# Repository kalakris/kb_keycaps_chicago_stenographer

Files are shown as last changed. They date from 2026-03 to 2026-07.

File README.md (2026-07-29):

<!-- omit from toc -->
# Chicago Stenographer Keycaps - Optimized for JLCPCB 3D printing

This fork combines multiple chicago stenographer keycaps with sprues into one file to get around the $1 minimum charge of JLCPCB.

If you like these keycaps after trying the 3D printed version, [consider buying original versions from the creator at asymplex.xyz](https://www.asymplex.xyz).

<!-- omit from toc -->
## Table Of Contents

- [1. Photos](#1-photos)
- [2. About this fork](#2-about-this-fork)
- [3. Documentation](#3-documentation)
  - [3.1. Keycap Types](#31-keycap-types)
    - [3.1.1. R2 Keycaps - Top](#311-r2-keycaps---top)
    - [3.1.2. R3 Keycaps - Middle rows and home row](#312-r3-keycaps---middle-rows-and-home-row)
    - [3.1.3. R4 Keycaps - Bottom](#313-r4-keycaps---bottom)
    - [3.1.4. Thumb Keycaps](#314-thumb-keycaps)
    - [3.1.5. 1.5u Thumb Key](#315-15u-thumb-key)
    - [3.1.6. Convex Keycaps](#316-convex-keycaps)
    - [3.1.7. Lateral Keycaps](#317-lateral-keycaps)
    - [3.1.8. Trapezoidal Sector Keycaps](#318-trapezoidal-sector-keycaps)
    - [3.1.9. Extended R5 Keys](#319-extended-r5-keys)
  - [3.2. What to print...](#32-what-to-print)
    - [3.2.1. If you have a 5x3 row board (Such as the corne without the outer coulmn)](#321-if-you-have-a-5x3-row-board-such-as-the-corne-without-the-outer-coulmn)
    - [3.2.2. If you have a 6x3 row board (Such as the corne WITH the outer coulmn)](#322-if-you-have-a-6x3-row-board-such-as-the-corne-with-the-outer-coulmn)
    - [3.2.3. If you have a 6x4 board with a num row...](#323-if-you-have-a-6x4-board-with-a-num-row)
  - [3.3. How to order on JLCPCB](#33-how-to-order-on-jlcpcb)
  - [3.4. How to create custom sets of keycaps](#34-how-to-create-custom-sets-of-keycaps)

## 1. Photos

Here are some photos of my prints using JLC 3DP's MJF PA12-HP Nylon process:

Chicago Stenographer 3D Print - MJF

Chicago Stenographer 3D Print - MJF

## 2. About this fork

This is a fork of [sporkus/PseudoMakeMeKeyCapProfiles](https://github.com/sporkus/PseudoMakeMeKeyCapProfiles/), which is a fork of [pseudoku's original chicago stenographer keycaps](https://github.com/pseudoku/PseudoMakeMeKeyCapProfiles).

Sporkus is the one who came up with the idea and the code to add spuers to the keycaps.

I expanded on those efforts in the following ways...

* Added support to generate rows of varying keycaps
* Fixed the 1.5u inner thumb key that is used in many corne-like boards
* Added the homing bar option to the lateral keys
* Added documentation on how to print the keycaps
* Fixed openscad warnings

Screenshot of thumbs stl

Screenshot of thumbs back stl

## 3. Documentation

### 3.1. Keycap Types

When I first started looking into these keycaps, I was incredibly confused by all the available keycap variations and files.

This repo is my attempt to simplify and document what I learned.

In the MX keycap world Rx is used to refer to rows and keycap heights. As someone who was only using Choc keycaps in the ergo keyboard world that was not intuitive for me at all.

But this graphic [from melgeek](https://www.melgeek.com/blogs/guide/the-type-of-keycaps-profiles) explains it well:
Keycap Rows

#### 3.1.1. R2 Keycaps - Top

You use these keycaps for the top row, but for the CS keycap set, both R2 and R4 are the same. You simply flip them around.

I also included pre-rotated keycaps as R4, but you can also just print R2 twice.

If your keyboard has a num row, you would use them for the num row and the bottom alpha row.

If you have a corne-style keyboard with just three rows, you would use it for the top and bottom alpha rows.

#### 3.1.2. R3 Keycaps - Middle rows and home row

You use these keycaps for the columns between the top and bottom rows.

If you have a num row, you would use it for the top alpha row and the homerow.

If you have a corne-style keyboard with just three rows, you would use it just for the home row.

#### 3.1.3. R4 Keycaps - Bottom

As explained in the R2 section, these are exactly the same as the R2 files, but pre-rotated.

You can order 2x R2 or 1x R2 + 1x R4.

#### 3.1.4. Thumb Keycaps

The thumb keycaps are designed to create a "dish" with ridges on the outer thumb keys.

The same model is used for the left and right keys, but it is mirrored. In this repo you will find a model that already has all the versions you will need.

If you have a corne-style thumb cluster with 3 keys, you can use a convex key for the middle one. It will act like a homing key.

And there is an alternative convex key included, which is slightly lower so that you can see which one you like better.

#### 3.1.5. 1.5u Thumb Key

Additionally, there are also 1.5u variations of the outer thumb keys.

You have to be very careful if you get the files from other repos, because by default the stem is rotated by 90 degrees unlike regular 1.5u keys.

The files here have the stem in the correct orientation for keyboards like the corne where the switch is already rotated by 90 degrees.

#### 3.1.6. Convex Keycaps

The convex keys are used on the middle thumb keys, but can also optionally be used on the inner and outer columns.

You can [see an example of how that looks here](https://www.printables.com/model/158865-chicago-steno-low-profile-ergo-keycaps).

#### 3.1.7. Lateral Keycaps

Steno keycaps have vertical ridges that keep your finger aligned in the row. This is great, but some people prefer to not have these ridges for the inner and outer columns so that they don't have to lift the finger to reach the side-key or to perform horizontal combos with one finger.

Keep in mind, that the lateral keycaps are used as a pair on two columns next to each other.

The file contains only one set of the two. If you want it on both sides of the keyboard, you have to print it twice.

I suggest printing one version with the homing dots and another with the homing bars to get all possible variations.

#### 3.1.8. Trapezoidal Sector Keycaps

For keyboards with splayed thumb keys arranged on a circular arc (such as the Go60), standard rectangular keycaps leave wedge-shaped gaps. The trapezoidal sector keycaps (`Choc_Chicago_Steno_Thumb_Trap.scad`) fill these gaps with sector-shaped footprints:

- Wider on the outer edge (away from arc center), narrower on the inner edge
- Arced outer/inner edges following the thumb arc curvature
- Radial side edges pointing toward the arc center

Three variants are available:

| Keycap ID | Position | Profile | Notes |
|---|---|---|---|
| `cs_t_trap_convex_t1` | T1 (innermost) | Convex dome | Symmetric 1.25u depth sector; inner edge aligned to C1 column above |
| `cs_t_trap_convex` | T2 (middle) | Convex dome | Symmetric 1.25u depth sector |
| `cs_t_trap_thumb_l/r` | T3 (outermost) | Thumb scoop | Symmetric 1.25u depth sector, L/R mirrored |

The arc geometry parameters (radius, angular spacing, gap) are configured in the file and default to Go60 measurements. Open `go60_visualization.scad` to see them in context.

#### 3.1.9. Extended R5 Keys

For boards where the splayed thumb row meets a row of straight-shifted keys, the extended R5 keys (`cs_r3x_1_ext_a`, `cs_r3x_1_ext_b` in `Choc_Chicago_Steno_Convex.scad`) extend the body downward so the bottom edge aligns with T1's inner edge:

| Keycap ID | Extension | Used for |
|---|---|---|
| `cs_r3x_1_ext_a` | +3.6mm | C4 R5 and C2 R5 columns |
| `cs_r3x_1_ext_b` | +6.5mm | C3 R5 column |

The body is symmetric (centered at `BodyOffsetY`) and the stem is offset to align with the switch position. From above, these look like standard symmetric convex keys; from the bottom, the stem is visibly off-center.

These are used in the V2 thumb row layout (`left_thumb_keys_v2` in `go60_visualization.scad`).

> **Known gap:** all three extended keys are convex, so V2 puts a dome on C2 R5.
> V1 (`left_thumb_keys`) deliberately uses a thumb dish (`cs_t_1_l`) there, since
> the thumb rests on T1 and reaches C2 R5 while C3/C4 R5 are finger keys. C2 R5 is
> convex in V2 only because `BodyOffsetY` lives in `Choc_Chicago_Steno_Convex.scad`
> and no extended thumb variant exists yet. Fixing it means porting `BodyOffsetY`
> into the thumb file, where the 7mm scoop is likely to spike the same way `ext_b`
> did.

### 3.2. What to print...

Look at the `export_*.scad` files to see what key models were used and further comments on how to use the sets. Render them with OpenSCAD to generate STL files (STLs are not checked into git due to size).

#### 3.2.1. If you have a 5x3 row board (Such as the corne without the outer coulmn)

* 1x `cs_row_r2_top.stl`
* 1x `cs_row_r3_homerow_bar.stl` or `cs_row_r3_homerow_dots.stl` (different homing keys)
  * Or the `cs_row_r3_regular.stl` and `cs_row_r3_homing_only.stl` to get both homing key variations
* 1x `cs_row_r4_bottom.stl`
* 1x `cs_row_thumbs.stl`

#### 3.2.2. If you have a 6x3 row board (Such as the corne WITH the outer coulmn)

All of the above, PLUS...

* 1x `cs_column_regular.stl` or `cs_column_convex.stl` for the outer pinky column

You can also print the `cs_column_regular_with_homing_bars.stl` variation which contains two more homing key.

Combine it with the `cs_row_r3_homerow_dots.scad` to get both homing key variations without needing to print them separately.

Alternatively, you can also consider the lateral variation, but this one needs to be printed twice as it should be used on both the outer and pinky keys.

The leeve rows can also be used for the index and inner column as the stl includes homing key variations.

To be able to use lateral keys on both sides and get both types of homing keys you should print...

* 1x `cs_column_lateral_homing_bar.stl`
* 1x `cs_column_lateral_homing_dot.stl`

#### 3.2.3. If you have a 6x4 board with a num row...

All of the above, PLUS...

* 1x `cs_row_r3_regular.stl` for the top alpha row (the r2 keycaps will be used for the num row)

#### 3.2.4. If you have a MoErgo Go60 (6x4 split columnar)

The Go60 has 6 columns x 4 rows per half plus a 6-key thumb cluster. C1, C2 (inner index pair) and C5, C6 (outer pinky pair) can each be printed in two styles — **lateral** (smooth side, easier to slide between adjacent columns) or **non-lateral** (ridged, like the rest of the steno set). Print one or both styles depending on preference; the table below covers both.

| File | Keys | Qty | Subtotal | Notes |
|---|---|-----|---|---|
| `export_go60_regular_columns.scad` | 10 | 4 | 40 | C3+C4 (×2 halves) + non-lateral C5+C6 (×2 halves). R1-R4 ridged + 2 spare convex thumbs. Render with CGAL. |
| `export_go60_regular_columns_homing.scad` | 10 | 2 | 20 | Non-lateral C1+C2 (×2 halves). R1-R4 ridged + homing bar + homing dot for C2 R3. |
| `export_go60_lateral_columns.scad` | 10 | 2 | 20 | Lateral C5+C6 (×2 halves). Lateral R1-R4 + 2 spare ridged thumbs. |
| `export_go60_inner_columns_left.scad` | 10 | 1 | 10 | Lateral C2+C1 left half. Lateral R1-R4 + homing bar + homing dot. |
| `export_go60_inner_columns_right.scad` | 10 | 1 | 10 | Lateral C2+C1 right half. Lateral R1-R4 + homing bar + homing dot. |
| `export_go60_thumbs.scad` | 10 | 1 | 10 | Main thumb cluster: ridged + convex + spare convex. Render with CGAL. |
| `export_go60_thumbs_alt.scad` | 10 | 1 | 10 | Alt thumb cluster: 8 convex R2 + 2 thumb 1.25u. Render with CGAL. |
| **Total (both styles)** | | | **120** | |

If you only want one style, drop the corresponding plates: skip the lateral plates (`lateral_columns`, `inner_columns_left`, `inner_columns_right`) for non-lateral only, or skip 4 of the 6 non-lateral plates (keep `regular_columns` ×2 for C3+C4) for lateral only.

Plates marked "Render with CGAL" contain convex keys that require the CGAL backend (`openscad --backend=CGAL`). Other plates can use the faster Manifold backend.

Open `go60_visualization.scad` in OpenSCAD to preview the full keyboard layout with all keys at their approximate positions. The visualization uses trapezoidal sector keycaps for the splayed thumb positions (T1, T2, T3) — see [Trapezoidal Sector Keycaps](#318-trapezoidal-sector-keycaps).

### 3.3. How to order on JLCPCB

* Upload the stl model
* Select 3D Technology: `MJF (Nylon)`
* Select Material: `PA12-HP Nylon`
* Optionally select Surface Finish: `Add - Dyeing - Dyed Black` to get black keycaps.
  * Without this they will be a "textured gray"
* Make sure to select the correct Quantity

The total for a 6x4 board with all the optional stuff will cost appoximately $23.88. In addition to that JLC now charges $1 per sprued file [as per their connected parts policy](https://jlc3dp.com/help/article/213-Connected-Parts-Printing-Guide).

So, it will be approximately $32.88 + shipping in total.

> [!NOTE]
> You will likely get warnings that some areas on the 1.5u thumb keys are too thin.
>
> You can just tell them that you accept the risk and it will print just fine. Me and several other people successfully printed these keycaps despite the warnings.
>
> The original code for the 1.5u thumb keys produced keycaps with the wrong stem orientation. I have attempted to fix this problem, but JLCPCB still complains about areas that are too thin and will ask you if you want to take the risk of them not getting printed correctly when you order.
>
> All other keycaps should not have problems though.

#### 3.3.1. JLCPCB Shopping Cart Example  <!-- omit from toc -->

JLCPCB Shopping Cart Example

### 3.4. How to create custom sets of keycaps

* Install OpenSCAD
  * The [snaphot version](https://openscad.org/downloads.html#snapshots) is recommended for performance reasons
  * If it crashes, [try an older version of the snapshot](https://files.openscad.org/snapshots/)
* Set up the dev environment
  * Adjust the Makefile with the path to your OpenSCAD installation
  * Unzip the `libraries.zip` into your [OpenSCAD library path](https://en.wikibooks.org/wiki/OpenSCAD_User_Manual/Libraries)
* Create your keycap set
  * Copy one of the files starting with `export_`
  * Adjust the keycaps you want to use. Available options are in `gen_sprued_keycaps.scad`
  * Keep in mind that jlcpcb only allows a maximum of 10 keycaps per file
* Generate STLs
  * Run `make` and it will generate all missing STLs
  * Alternatively you can also select which file to generate by running something like `make stl/cs_row_thumbs.stl`, but keep in mind that you have to use the file name of the final stl file and not of the source `.scad` file
  * STLs are exported in binary format (`--export-format binstl`) which is ~6x smaller than ASCII STL. If you render manually, add this flag to keep file sizes manageable (e.g. ~40 MB vs ~250 MB for a 10-key plate).

Alternatively you can also run the GUI version, but it's a bit slow.

You can speed it up by enabling the `manifold` options in `Preferences -> Features` (Snapshot version only).

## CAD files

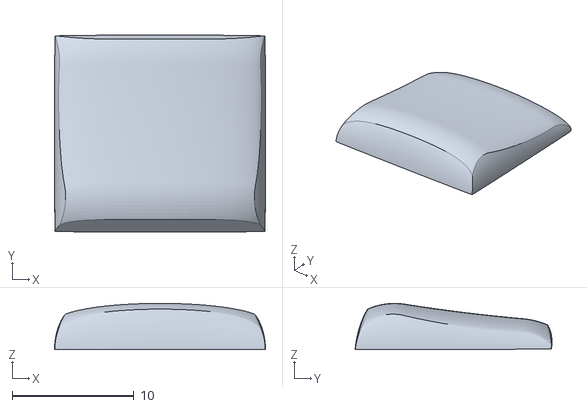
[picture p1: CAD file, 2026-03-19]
stl/single_keys/cs_r4x_1.stl
17.3 x 16.2 x 3.79

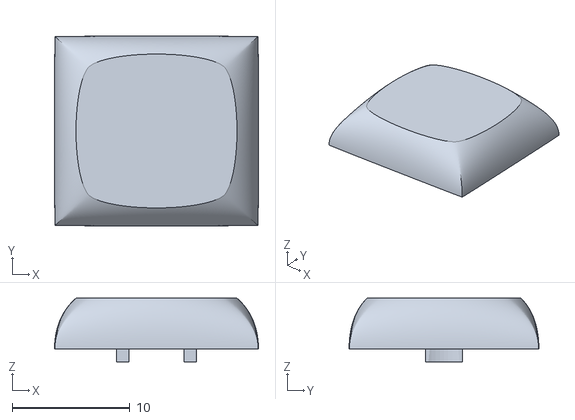
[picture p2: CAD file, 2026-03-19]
stl/single_keys/cs_r3x_1.stl
17.3 x 16.1 x 5.41

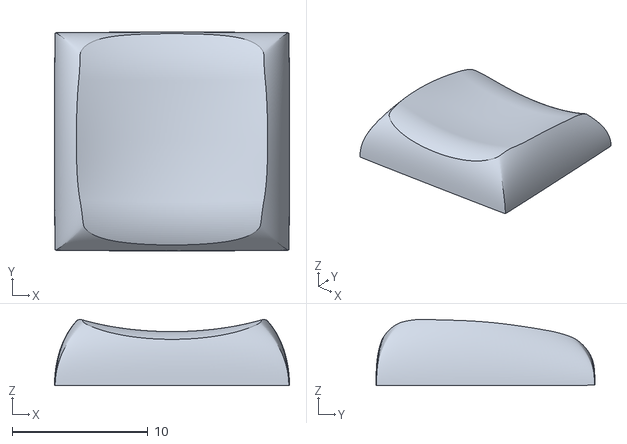
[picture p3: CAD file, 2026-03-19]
stl/single_keys/cs_r4_1.stl
17.3 x 16.1 x 4.88

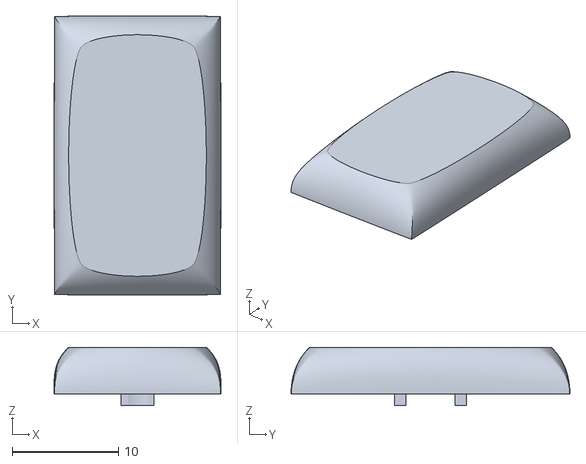
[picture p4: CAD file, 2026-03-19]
stl/single_keys/cs_r3_15.stl
15.7 x 26.3 x 5.51

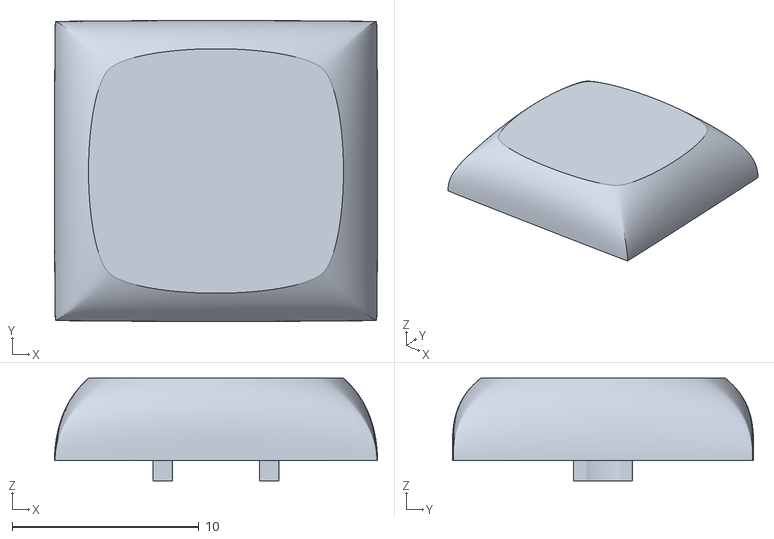
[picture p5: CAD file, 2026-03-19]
stl/single_keys/cs_r3_1.stl
17.3 x 16.1 x 5.51

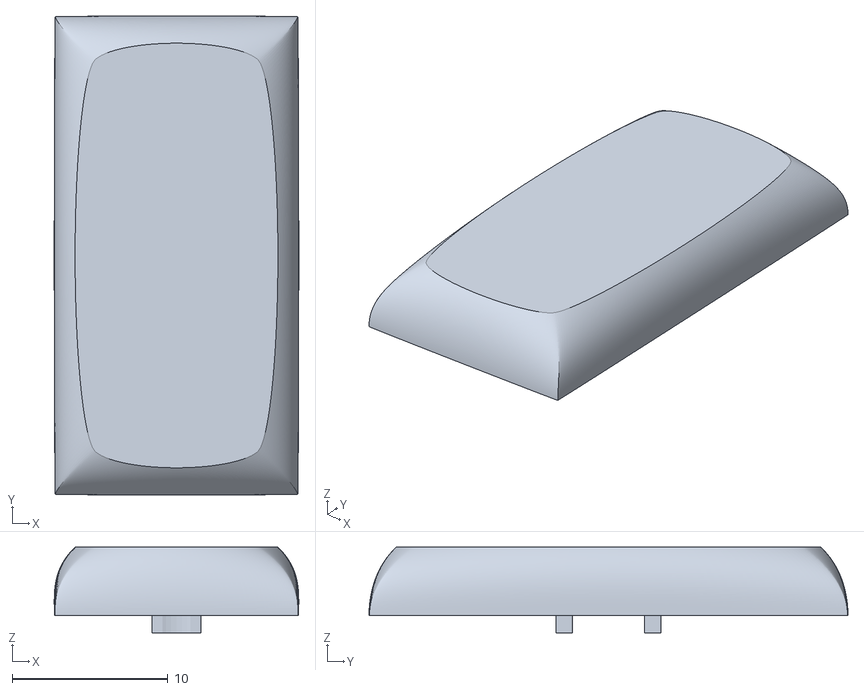
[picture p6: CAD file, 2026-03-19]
stl/single_keys/cs_r3_175.stl
15.7 x 30.8 x 5.51

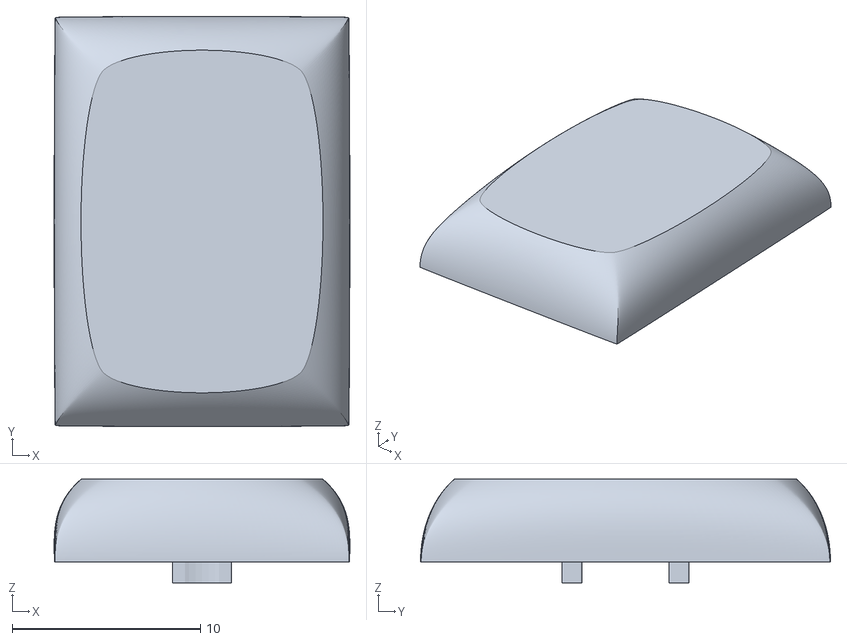
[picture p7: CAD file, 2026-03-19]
stl/single_keys/cs_r3_125_bar.stl
15.7 x 21.8 x 5.51

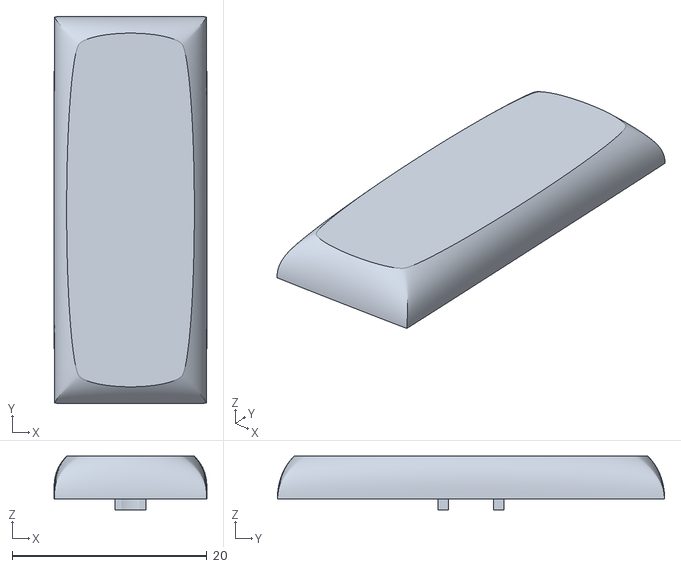
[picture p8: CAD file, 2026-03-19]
stl/single_keys/cs_r3_225.stl
15.7 x 39.8 x 5.51

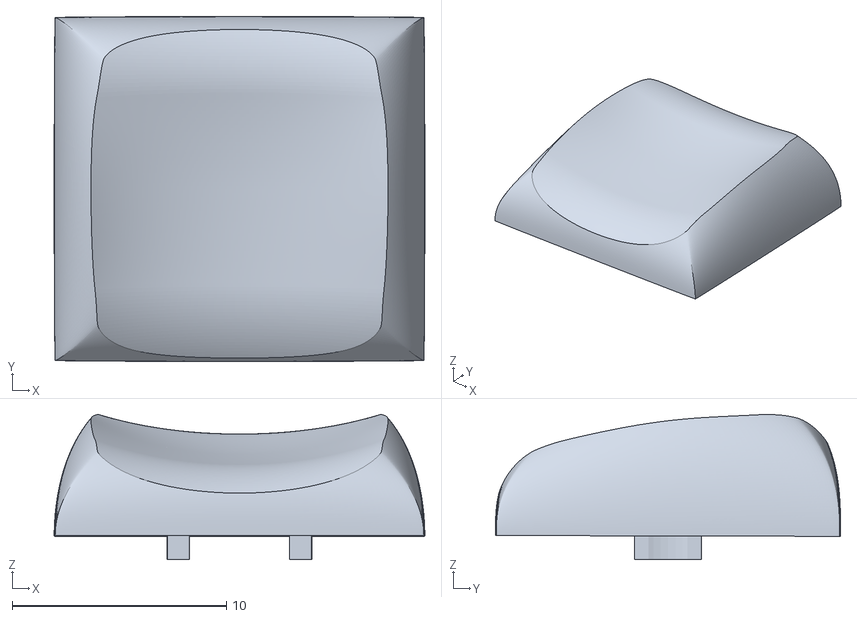
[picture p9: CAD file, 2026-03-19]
stl/single_keys/cs_r1_1.stl
17.3 x 16.1 x 6.77

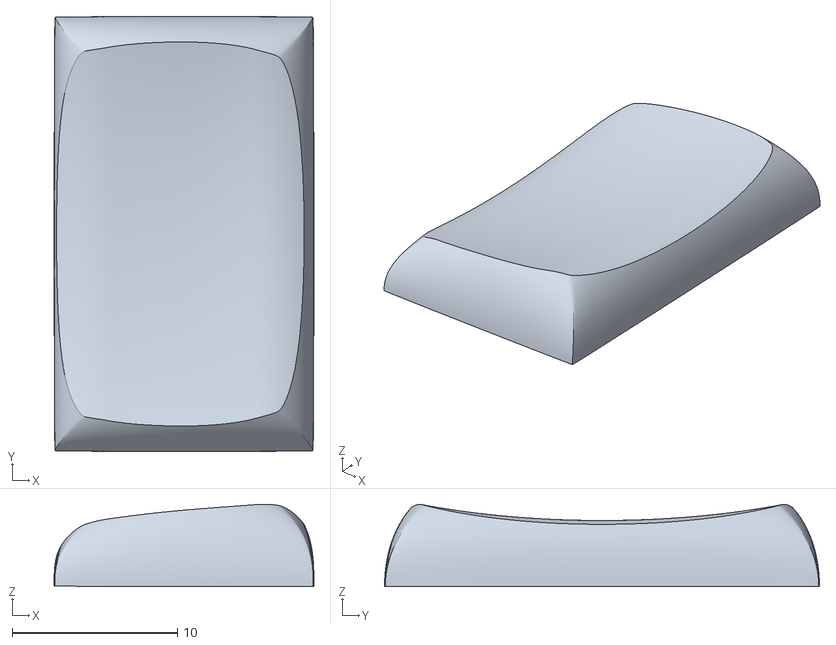
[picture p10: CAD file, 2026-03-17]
stl/single_keys/cs_r2_15.stl
15.7 x 26.3 x 4.98

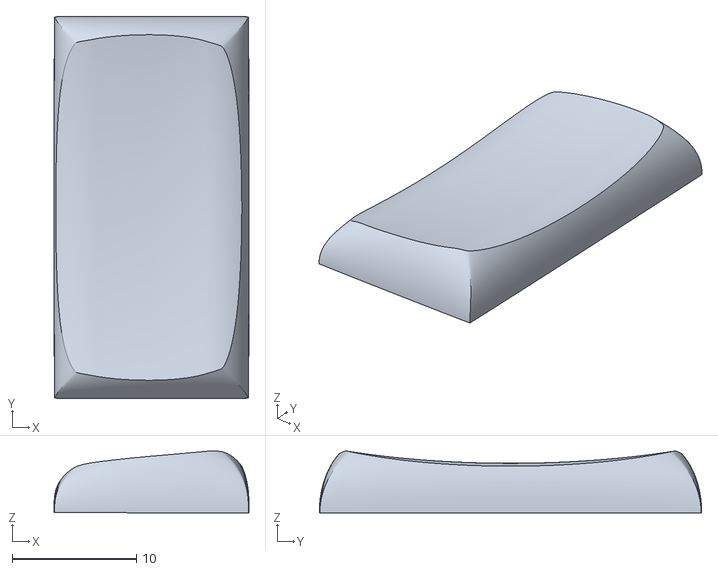
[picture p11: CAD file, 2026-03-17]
stl/single_keys/cs_r2_175.stl
15.7 x 30.8 x 4.99

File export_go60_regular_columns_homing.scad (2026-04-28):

// Go60 - Regular columns with homing keys (non-lateral C1+C2)
//
// Same finger-key layout as export_go60_regular_columns.scad (ridged
// R1-R4 for two columns) but the 2 trailing slots are swapped from
// spare convex thumbs to homing-bar and homing-dot variants of cs_r3_1.
//
// Use for the non-lateral version of C1+C2 (inner index pair). Each
// half needs one homing key on C2 R3 (the F / J position); print 2 of
// these plates so each half can pick bar or dot.
//
// 10 keys: 8 finger (R1-R4 x 2 columns) + 1 homing bar + 1 homing dot
// Order quantity: 2 (one per keyboard half)

use <gen_sprued_keycaps.scad>

keycap_ids = [
    // Left column of pair
    "cs_r1_1",      // Row 1 (top)
    "cs_r2_1",      // Row 2
    "cs_r3_1",      // Row 3 (home) - spare, replaced by bar or dot
    "cs_r4_1",      // Row 4 (bottom)

    // Right column of pair
    "cs_r1_1",      // Row 1 (top)
    "cs_r2_1",      // Row 2
    "cs_r3_1",      // Row 3 (home) - spare, replaced by bar or dot
    "cs_r4_1",      // Row 4 (bottom)

    // Homing options for C2 R3 (pick one per half)
    "cs_r3_1_bar",  // C2 homing bar
    "cs_r3_1_dot",  // C2 homing dot
];

gen_sprued_keycaps(keycap_ids, vertical=true);

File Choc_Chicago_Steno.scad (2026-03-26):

use <scad-utils/morphology.scad> //for cheaper minwoski
use <scad-utils/transformations.scad>
use <scad-utils/shapes.scad>
use <scad-utils/trajectory.scad>
use <scad-utils/trajectory_path.scad>
use <sweep.scad>
use <skin.scad>
//use <z-butt.scad>

//Choc Chord version Chicago Stenographer

/*Tester */
keycap_cs(
  keyID  = 6, //change profile refer to KeyParameters Struct
  cutLen = 0, //Don't change. for chopped caps
  Stem   = true, //tusn on shell and stems
  StemRot = 0, //change stem orientation by deg
  Dish   = true, //turn on dish cut
  Stab   = 0,
  visualizeDish = false, // turn on debug visual of Dish
  crossSection  = false, // center cut to check internal
  homeDot = false, //turn on homedots,
  homeBar = true, //turn on homebar,
  Legends = false
  );

//-Parameters
wallthickness = 1.1; // 1.75 for mx size, 1.1
topthickness = 3.0; //2 for phat 3 for chicago
stepsize = 50;  //resolution of Trajectory
step = 0.5;       //resolution of ellipes
fn = 60;          //resolution of Rounded Rectangles: 60 for output
layers = 50;    //resolution of vertical Sweep: 50 for output

//---Stem param
slop    = 0.3;
stemRot = 0;
stemWid = 8;
stemLen = 6;
stemCrossHeight = 1.8;
extra_vertical = 0.6;
stemLayers = 50; //resolution of stem to cap top transition
//#cube([18.16, 18.16, 10], center = true); // sanity check border

//injection param
draftAngle = 0; //degree  note:Stem Only
//TODO: Add wall thickness transition?


keyParameters = //keyParameters[KeyID][ParameterID]
[
//  BotWid, BotLen, TWDif, TLDif, keyh, WSft, LSft  XSkew, YSkew, ZSkew, WEx, LEx, CapR0i, CapR0f, CapR1i, CapR1f, CapREx, StemEx
    //Column 0
    //Levee: Chicago in choc Dimension
    [17.20,  16.00,   5.6, 	   5,  4.9,    0,   .0,     5,    -0,    -0,   2, 2.5,    .10,      2,     .10,      3,     2,       2], //Chicago Steno R2/R4
    [17.20,  16.00,   5.6, 	   5,  4.5,    0,   .0,     0,    -0,    -0,   2, 2.5,    .10,      3,     .10,      3,     2,       2], //Chicago Steno R3 flat
    [17.20,  16.00,  1.25, 	1.25,  4.5,    0,   .0,     0,    -0,    -0,   2, 2.5,    .10,     .5,     .10,     .5,     2,       2], //Chicago Steno R3 chord
    //mods 3
    [17.20,  16.00,  4.25, 	3.25,  5.5,  -.7,  0.7,     0,    -4,    -0,   2,   2,    .10,      2,     .10,      2,     2,       2], //Levee Corner R2
    [17.20,  16.00,  4.25, 	3.25,  5.2,  -.8,  0.6,     0,    -4,    -0,   2,   3,    .10,      2,     .10,      2,     2,       2], //Levee Corner R2
    //1.25: [5, 6]
    [21.7,   15.60,  5.6, 	   5,  4.9,    0,   .0,     5,    -0,    -0,   2, 2.5,     .1,      2,      .1,      3,     2,       2], //Chicago Steno R2/R4 1.25u
    [21.7,   15.60,  5.6, 	   5,  4.5,    0,   .0,     0,    -0,    -0,   2, 2.5,     .1,      3,      .1,      3,     2,       2], //Chicago Steno R3 1.25u
    //1.5: [7, 8]
    [26.20,  15.60,   5.6, 	   5,  4.9,    0,   .0,     5,    -0,    -0,   2, 2.5,     .1,      2,      .1,      3,     2,       2], //Chicago Steno R2/R4 1.5
    [26.20,  15.60,   5.6, 	   5,  4.5,    0,   .0,     0,    -0,    -0,   2, 2.5,     .1,      3,      .1,      3,     2,       2], //Chicago Steno R3 1.5u
    //1.75: [9, 10]
    [30.70,  15.60,   5.6, 	   5,  4.9,    0,   .0,     5,    -0,    -0,   2, 2.5,     .1,      2,      .1,      3,     2,       2], //Chicago Steno R2/R4 1.5
    [30.70,  15.60,   5.6, 	   5,  4.5,    0,   .0,     0,    -0,    -0,   2, 2.5,     .1,      3,      .1,      3,     2,       2], //Chicago Steno R3 1.5u
    //2.00: [11, 12]
    [35.20,  15.60,   5.6, 	   5,  4.9,    0,   .0,     5,    -0,    -0,   2, 2.5,     .1,      2,      .1,      3,     2,       2], //Chicago Steno R2/R4 1.5
    [35.20,  15.60,   5.6, 	   5,  4.5,    0,   .0,     0,    -0,    -0,   2, 2.5,     .1,      3,      .1,      3,     2,       2], //Chicago Steno R3 1.5u
    //2.25: [13, 14]
    [39.70,  15.60,   5.6, 	   5,  4.9,    0,   .0,     5,    -0,    -0,   2, 2.5,     .1,      2,      .1,      3,     2,       2], //Chicago Steno R2/R4 1.5
    [39.70,  15.60,   5.6, 	   5,  4.5,    0,   .0,     0,    -0,    -0,   2, 2.5,     .1,      3,      .1,      3,     2,       2], //Chicago Steno R3 1.5u
    // Ergo shits
    [18.75,  18.75,   5.6, 	   5,    8,    0,   .25,     0,    -0,    -0,   2, 2.5,    .10,      3,     .10,      3,     2,       2], //highpro 19.05 R2|4
    [17.20,  16.00,   5.6, 	   5,  4.7,    0,   .0,      3,    -0,    -0,   2, 2.5,    .10,      2,     .10,      3,     2,       2], //Chicago Steno R2 ALT
    [17.20,  16.00,   5.6, 	   5,  5.5,    0,   .0,      7,    -0,    -0,   2, 2.5,    .10,      2,     .10,      3,     2,       2], //Chicago Steno R1 Steap
    [17.20,  16.00,   5.6, 	   5,  7.0,    0,   .0,     10,    -0,    -0,   2, 2.5,    .10,      2,     .10,      3,     2,       2] //Chicago Steno R1 mild with alt R2
];

dishParameters = //dishParameter[keyID][ParameterID]
[
//FFwd1 FFwd2 FPit1 FPit2  DshDep DshHDif FArcIn FArcFn FArcEx     BFwd1 BFwd2 BPit1 BPit2  BArcIn BArcFn BArcEx
  //Column 0
  [ 4.5,    4,    7,  -50,      7,    1.7,   11.5,    17.5,     2,      4.5,    4,    2,   -35,   11.5,  15,     2], //Chicago Steno R2/R4
  [ 4.5,    4,    5,  -40,      7,    1.7,   11.5,    15,     2,      4.5,    4,    5,   -40,   11.5,    15,     2], //Chicago Steno R3 flat
  [ 4.5,    4,    5,  -40,      7,    1.7,   11.5,    15,     2,      4.5,    4,    5,   -40,   11.5,    15,     2], //Chicago Steno R3 chord

  [   6,  3.5,    7,  -50,      5,    1.0,   16,    23,     2,        6,  3.5,    7,   -50,   16,    23,     2], //Levee Steno R2/R4
  [   6,  3.5,    7,  -50,      5,    1.0,   16,    23,     2,        6,  3.5,    7,   -50,   16,    23,     2], //Levee Steno R2/R4
  //1.25
  [ 4.5,    4,    7,  -40,      8,    1.7,   16.0,  22.5,     2,      4.5,    4,    2,   -35,   16.0,  19.5,     2], //Chicago Steno R2/R4
  [ 4.5,    4,    5,  -40,      8,    1.7,   16.0,  19.5,     2,      4.5,    4,    5,   -40,   16.0,  19.5,     2], //Chicago Steno R3
  //1.5
  [ 4.5,    4,    7,  -40,      8,    1.7,   20.5,  26.5,     2,      4.5,    4,    2,   -35,   20.5,  24.0,     2], //Chicago Steno R2/R4
  [ 4.5,    4,    5,  -40,      8,    1.7,   20.5,  24.0,     2,      4.5,    4,    5,   -40,   20.5,  24.0,     2], //Chicago Steno R3
  //1.75
  [ 4.5,    4,    7,  -40,      8,    1.7,   25.0,  31.0,     2,      4.5,    4,    2,   -35,   25.0,  28.5,     2], //Chicago Steno R2/R4
  [ 4.5,    4,    5,  -40,      8,    1.7,   25.0,  28.5,     2,      4.5,    4,    5,   -40,   25.0,  28.5,     2], //Chicago Steno R3
  //2.00
  [ 4.5,    4,    7,  -40,      8,    1.7,   29.5,  35.5,     2,      4.5,    4,    2,   -35,   29.5,  33.0,     2], //Chicago Steno R2/R4
  [ 4.5,    4,    5,  -40,      8,    1.7,   29.5,  33.0,     2,      4.5,    4,    5,   -40,   29.5,  33.0,     2], //Chicago Steno R3
  //2.25
  [ 4.5,    4,    7,  -40,      8,    1.7,   33.0,  39.0,     2,      4.5,    4,    2,   -35,   33.0,  36.5,     2], //Chicago Steno R2/R4
  [ 4.5,    4,    5,  -40,      8,    1.7,   33.0,  36.5,     2,      4.5,    4,    5,   -40,   33.0,  36.5,     2], //Chicago Steno R3

  [   5,    5,    5,  -40,      7,    1.7,   11,    15,     2,        5,    5,    5,   -40,   11,    15,     2], //Chicago Steno R3 flat
  [ 4.5,    4,    7,  -50,      7,    1.7,   11,    17,     2,      4.5,    4,    2,   -35,   11,    15,     2], //Chicago Steno R1
  [ 4.5,    4,    7,  -50,      7,    1.7,   11,    17,     2,      4.5,    4,    2,   -35,   11,    15,     2], //Chicago Steno R1
  [ 4.5,    4,    7,  -50,      7,    1.7,   11,    17,     2,      4.5,    4,    2,   -35,   11,    15,     2] //Chicago Steno R1
];


function BottomWidth(keyID)  = keyParameters[keyID][0];  //
function BottomLength(keyID) = keyParameters[keyID][1];  //
function TopWidthDiff(keyID) = keyParameters[keyID][2];  //
function TopLenDiff(keyID)   = keyParameters[keyID][3];  //
function KeyHeight(keyID)    = keyParameters[keyID][4];  //
function TopWidShift(keyID)  = keyParameters[keyID][5];
function TopLenShift(keyID)  = keyParameters[keyID][6];
function XAngleSkew(keyID)   = keyParameters[keyID][7];
function YAngleSkew(keyID)   = keyParameters[keyID][8];
function ZAngleSkew(keyID)   = keyParameters[keyID][9];
function WidExponent(keyID)  = keyParameters[keyID][10];
function LenExponent(keyID)  = keyParameters[keyID][11];
function CapRound0i(keyID)   = keyParameters[keyID][12];
function CapRound0f(keyID)   = keyParameters[keyID][13];
function CapRound1i(keyID)   = keyParameters[keyID][14];
function CapRound1f(keyID)   = keyParameters[keyID][15];
function ChamExponent(keyID) = keyParameters[keyID][16];
function StemExponent(keyID) = keyParameters[keyID][17];
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

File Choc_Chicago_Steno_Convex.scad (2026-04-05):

use <scad-utils/morphology.scad> //for cheaper minwoski
use <scad-utils/transformations.scad>
use <scad-utils/shapes.scad>
use <scad-utils/trajectory.scad>
use <scad-utils/trajectory_path.scad>
use <sweep.scad>
use <skin.scad>
//use <z-butt.scad>

//NOTE: with sweep cuts, top surface may not be visible in review, it should be visible once rendered
//
// RENDERING: Must use CGAL backend (--backend=CGAL). The Manifold backend
// cannot handle the two-sweep dish boolean — it produces high genus meshes
// with visible artifacts and incorrect dish geometry.
//
// The convex dish uses two separate skin() sweeps (front + back) with
// different rotations. This is inherently problematic for Manifold but
// CGAL handles it correctly.
//
// R3x keys have XAngleSkew=0.01 (was 0) to work around a CGAL assertion
// failure in OpenSCAD 2026 where perfectly symmetric front/back dish
// sweeps create degenerate geometry. The 0.01° perturbation is imperceptible.

mirror([0,0,0])keycap_cs_convex(
  keyID  = 2, //change profile refer to KeyParameters Struct
  cutLen = 0, //Don't change. for chopped caps
  Stem   = true, //tusn on shell and stems
  StemRot = 0,//change stem orientation by deg
  Dish   = true, //turn on dish cut
  Stab   = 0,
  visualizeDish = true, // turn on debug visual of Dish
  crossSection  = false, // center cut to check internal
  homeDot = false, //turn on homedots
  Legends = false
);

//Parameters
wallthickness = 1.2;
topthickness  = 2;   //
stepsize      = 50;  //resolution of Trajectory
step          = 1;   //resolution of ellipes
fn            = 60;  //resolution of Rounded Rectangles: 60 for output
layers        = 50;  //resolution of vertical Sweep: 50 for output
dotRadius     = 1.25;   //home dot size
//---Stem param
slop    = 0.25;
stemWid = 8;
stemLen = 6;
stemCrossHeight = 1.8;
extra_vertical  = 0.6;
StemBrimDep     = 0;
stemLayers      = 50; //resolution of stem to cap top transition
driftAngle      = 0;

keyParameters = //keyParameters[KeyID][ParameterID]
[
//  BotWid, BotLen, TWDif, TLDif, keyh, WSft, LSft  XSkew, YSkew, ZSkew, WEx, LEx, CapR0i, CapR0f, CapR1i, CapR1f, CapREx, StemEx
    //Column 0
    //Levee: Chicago in choc Dimension 0-3
    [17.20,  16.00,   5.6, 	   5,  3.8,    0,  -.5,     7,    -0,    -0,   2, 2,    .10,      3,     .10,      3,     2,       2], //Chicago Steno R2x 1u
    [17.20,  16.00,   5.6, 	   5,  4.4,    0,   .0,  0.01,    -0,    -0,   2, 2,    .10,      3,     .10,      3,     2,       2], //Chicago Steno R3x 1u

    // R3x 1.25~2.25u [4:8]
    [21.7,   15.60,   5.6, 	   5.6,  4.5,   0,   .0, 0.01,    -0,    -0,   2, 2.5,   .1,      3,     .1,      3,     2,       2], //Chicago Steno R3x 1.25u
    [26.20,  15.60,   5.6, 	   5.6,  4.5,   0,   .0, 0.01,    -0,    -0,   2, 2.5,   .1,      3,     .1,      3,     2,       2], //Chicago Steno R3x 1.5u
    [30.70,  15.60,   5.6, 	   5.6,  4.5,   0,   .0, 0.01,    -0,    -0,   2, 2.5,   .1,      3,     .1,      3,     2,       2], //Chicago Steno R3x 1.75u
    [35.20,  15.60,   5.6, 	   5.6,  4.5,   0,   .0, 0.01,    -0,    -0,   2, 2.5,   .1,      3,     .1,      3,     2,       2], //Chicago Steno R3x 2.0u
    [39.70,  15.60,   5.6, 	   5.6,  4.5,   0,   .0, 0.01,    -0,    -0,   2, 2.5,   .1,      3,     .1,      3,     2,       2], //Chicago Steno R3x 2.25u

    // Extended R5 keys: symmetric body centered at BodyOffsetY, stem at switch (y=0).
    // Body+dish look symmetric from above. Stem transition bridges from stem to body.
    //                                                                                                                                     BodyOffsetY
    [17.20,  19.60,   5.6,      5,  4.4,   0,   .0, 0.01,    -0,    -0,   2, 2,    .10,      3,     .10,      3,     2,       2,  -1.80], // 7: R3x ext-A (C4/C2 R5, +3.6mm down)
    [17.20,  22.50,   5.6,      5,  4.4,   0,   .0, 0.01,    -0,    -0,   2, 2,    .10,      3,     .10,      3,     2,       2,  -3.25], // 8: R3x ext-B (C3 R5, +6.5mm down)

//  original from pseudo, mislabled/ missing params?
//    [35.85,  15.65,     7, 	   7,  4.4,    0,   .0,     0,    -0,    -0,   2, 2,    .30,      5,     .30,      5,     2,       2], //Chicago Steno R3x 2u
//    [35.85,  15.65,     7, 	   7,  4.4,    0,   .0,     0,    -0,    -0,   2, 2,    .30,      5,     .30,      5,     2,       2], //Chicago Steno R3x 2u
//    //mods 3
//    [17.20,  16.00,  4.25, 	3.25,  5.5,  -.7,  0.7,     0,    -4,    -0,   2,   2,    .10,      2,     .10,      2,     2,       2], //Levee Corner R2
//    [17.20,  16.00,  4.25, 	3.25,  5.2,  -.8,  0.6,     0,    -4,    -0,   2,   3,    .10,      2,     .10,      2,     2,       2], //Levee Corner R2
//    //1.25 5
//    [21.3,   15.60,  5.6, 	   5,  4.5,    0,   .0,     5,    -0,    -0,   2,   2,     .5,      3,      .5,      3,     2,       2], //Chicago Steno R2/R4 1.25u
//    [21.4,   15.60,  5.6, 	   5,  4.5,    0,   .0,     0,    -0,    -0,   2,   2,     .5,      3,      .5,      3,     2,       2], //Chicago Steno R3 1.25u
//    //1.5 7
//    [26.15,  15.60,   5.6, 	   5,  4.5,    0,   .0,     5,    -0,    -0,   2,   2,     .5,      3,      .5,      3,     2,       2], //Chicago Steno R2/R4 1.5
//    [26.15,  15.60,   5.6, 	   5,  4.5,    0,   .0,     0,    -0,    -0,   2,   2,     .5,      3,      .5,      3,     2,       2], //Chicago Steno R3 1.5u
//    //1.75 9
//    [30.90,  15.60,   5.6, 	   5,  4.5,    0,   .0,     5,    -0,    -0,   2,   2,     .5,      3,      .5,      3,     2,       2], //Chicago Steno R2/R4 1.5
//    [30.90,  15.60,   5.6, 	   5,  4.5,    0,   .0,     0,    -0,    -0,   2,   2,     .5,      3,      .5,      3,     2,       2], //Chicago Steno R3 1.5u
//    // Ergo shits
//    [18.75,  18.75,   5.6, 	   5,    8,    0,   .25,     0,    -0,    -0,   2, 2.5,    .10,      3,     .10,      3,     2,       2], //highpro 19.05 R2|4
//    [17.20,  16.00,   5.6, 	   5,  4.7,    0,   .0,      3,    -0,    -0,   2, 2.5,    .10,      2,     .10,      3,     2,       2], //Chicago Steno R2 ALT
//    [17.20,  16.00,   5.6, 	   5,  5.5,    0,   .0,      7,    -0,    -0,   2, 2.5,    .10,      2,     .10,      3,     2,       2], //Chicago Steno R1 Steap
//    [17.20,  16.00,   5.6, 	   5,  7.0,    0,   .0,     10,    -0,    -0,   2, 2.5,    .10,      2,     .10,      3,     2,       2], //Chicago Steno R1 mild with alt R2
];

dishParameters = //dishParameter[keyID][ParameterID]
[
//FFwd1 FFwd2 FPit1    FPit2  DshDepi    DshHDif FArcIn  FArcFn FArcEx  BFwd1 BFwd2 BPit1 BPit2  BArcIn BArcFn BArcEx
  [   5,  2.3,    2,     -55,    1.5,    3.75,     8.5,    8.5,    2,      5,    3,    2,  -50,    8.5,    8.7 ,     2], //R2x 1u
  [ 4.5,  3.3,   -3,     -45,    1.5,    3.75,     8.5,    8.7,    2,    4.5,  3.3,   -3,  -45,    8.5,   8.7,     2], //R3x 1u

  // R3x 1.25~2.25u [4:8]
  [ 4.5,  3.2,   -7,     -45,    1.5,    3.75,    10.75,   10.95,  2,    4.5,  3.2,   -7,  -45,   10.75,   10.95,  2], //R3x 1.25u
  [ 4.5,  3.2,   -7,     -45,    1.5,    3.75,    13.00,   13.20,  2,    4.5,  3.2,   -7,  -45,   13.00,   13.20,  2], //R3x 1.5u
  [ 4.5,  3.2,   -7,     -45,    1.5,    3.75,    15.25,   15.45,  2,    4.5,  3.2,   -7,  -45,   15.25,   15.45,  2], //R3x 1.75u
  [ 4.5,  3.2,   -7,     -45,    1.5,    3.75,    17.50,   17.70,  2,    4.5,  3.2,   -7,  -45,   17.50,   17.70,  2], //R3x 2.00u
  [ 4.5,  3.2,   -7,     -45,    1.5,    3.75,    19.75,   19.95,  2,    4.5,  3.2,   -7,  -45,   19.75,   19.95,  2], //R3x 2.25u

  // Extended R5 keys: symmetric body, dish centered on body (shifted by BodyOffsetY).
  // Symmetric front/back sweeps. pitch=-3 (like R3x 1u) for smooth dome curvature.
  [  8,  4,   -3,     -45,    1.5,    3.75,     8.5,    8.7,    2,     8,    4,   -3,  -45,    8.5,    8.7,    2], // 7: R3x ext-A (symmetric, half-len 9.8)
  [ 10,  5,   -3,     -45,    1.5,    3.75,     8.5,    8.7,    2,    10,    5,   -3,  -45,    8.5,    8.7,    2], // 8: R3x ext-B (symmetric, half-len 11.25)

//  original from pseudo, mislabled/ missing params?
//  [ 4.5,  3.2,   -5,  -45,    1.5,   3.75,  19.0,    18,     2,     4.5,  3.2,   -5,  -45,   19.0,    18,     2], //R3x 2u
//  [ 4.5,  3.2,   -5,  -45,    1.5,   3.75,  19.0,    18,     2,     4.5,  3.2,   -5,  -45,   19.0,    18,     2], //R3x 2u
//  ---
//  [   4,  4.2,   -5,  -15,      1,      3,  18.2,    21,     2,       5,    3,   -5,  -15,   18.2,    21,     2], //R3 2u
//  [  4.,  1.5,    8,  -55,      3,      7,   9.0,     9,     2,       4,    3,    3,  -50,    9,     9,     2],  //R3
//  [  4.,  1.5,   -0,  -50,      3,      7,   9.0,     9,     2,       4,    3,    -10,  -50,    9,     9,     2],  //R3
//  [   5,  3.5,    8,  -50,      5,    1.8,   8.8,    15,     2,       6,    4,   13,   30,    8.8,    16,     2], //R1
];
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

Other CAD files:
stl/single_keys/cs_r3_125_dot.stl
stl/single_keys/cs_r3_1_dot.stl
stl/single_keys/cs_r3_125.stl
stl/single_keys/cs_r3_1_bar.stl
stl/single_keys/cs_r2x_1.stl
stl/single_keys/cs_r2_1.stl
Choc_Chicago_Steno_Thumb.scad
Choc_Chicago_Steno_Thumb_Trap.scad
export_go60_inner_columns_left.scad
export_go60_inner_columns_right.scad
export_go60_lateral_columns.scad
export_go60_regular_columns.scad
export_go60_thumbs.scad
export_go60_thumbs_alt.scad
gen_sprued_keycaps.scad
go60_visualization.scad
stl/single_keys/cs_r2_125.stl
test_ext.scad
test_trap.scad
view_stl.scad

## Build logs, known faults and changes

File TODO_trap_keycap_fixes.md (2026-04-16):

# Trapezoidal & Extended Keycap Notes

Notes on the trapezoidal sector keycaps (T1/T2/T3) and the extended R5 keys
(ext_a/ext_b) used in the Go60 V2 thumb row.

## Background

The Go60 keyboard has splayed thumb keys arranged on a circular arc. Standard
rectangular keycaps leave wedge-shaped gaps. Two solutions are implemented:

1. **Trapezoidal sector keycaps** (T1/T2/T3) fill the splayed positions with
   sector-shaped footprints. See README.md section 3.1.8.
2. **Extended R5 keys** (ext_a/ext_b) extend the straight thumb row keys
   downward so their bottoms align with T1's inner edge at y=-57.

## Status: ALL KEYS WORKING

| Key | keyID | File | Status |
|---|---|---|---|
| T1 | 2 | Choc_Chicago_Steno_Thumb_Trap.scad | clean (CGAL Vol=2) |
| T2 | 0 | Choc_Chicago_Steno_Thumb_Trap.scad | clean (CGAL Vol=2) |
| T3 | 1 | Choc_Chicago_Steno_Thumb_Trap.scad | clean (CGAL Vol=2) |
| ext_a | 7 | Choc_Chicago_Steno_Convex.scad | clean (CGAL Vol=2) |
| ext_b | 8 | Choc_Chicago_Steno_Convex.scad | clean (CGAL Vol=2) |

## Trap Key Architecture

```
intersection() {
    (oversized_elliptical_rectangle_body - inner + stem) - dish_cut,
    sector_rectangle_skin  // trim to sector footprint
}
```

- Oversized smooth body (+14mm per dimension) ensures the dish boolean operates
  on smooth surfaces only — no dish-corner artifacts.
- Sector trim (skin of sector_rectangle cross-sections) clips to the exact
  sector footprint.
- The dish only touches smooth geometry; the sector only clips smooth results.

### Trap dish parameters

**T2 (keyID 0, dish row 0)**: arc gradient 10.5→13, pitch=-3/-45, FFwd=8+6, BFwd=7+5
- Tight arc at center (visible dome), wide at edges (corner coverage)

**T1 (keyID 2, dish row 1)**: uniform arc 13.0/13.2, pitch=-3/-45, FFwd=8+6, BFwd=7+5
- Wide uniform arc needed because left_line extends sector to x≈-12.4mm
- pitch=-3 (not 0) provides smooth dome curvature along the sweep
- Symmetric depth (depth_ratio=[1,1], BotLen=20)

**T3 (keyID 1)**: thumb scoop, FFwd=9+7 pitch=0/-40, BFwd=9+5.5 pitch=5/-50, arcs=20/24
- Fully extended to cover skew-raised corners (XSkew=-3, YSkew=-3)

### T1 known minor issue

Tiny notch at the bottom corner from the left_line creating an asymmetric
sector polygon whose skin() between layers produces a small artifact.
Confirmed by disabling left_line → notch disappears. NOT a dish coverage issue.
Considered acceptable — not visible from the top/typing perspective.

## Extended R5 Architecture (ext_a / ext_b)

Symmetric body centered at BodyOffsetY, stem at switch (y=0). Body+dome look
symmetric from above, stem simply offset below.

**Implementation in Choc_Chicago_Steno_Convex.scad:**
- `CapTranslation` / `InnerTranslation`: constant `BodyOffsetY` at all heights
- `StemTranslation`: tapers from y=0 (stem) to y=BodyOffsetY (inner shell top),
  bridging the gap inside the body
- Dish positioning: shifted by `BodyOffsetY` to center on body
- Dish params: symmetric front/back sweeps, pitch=-3, arcs=8.5/8.7 (matching R3x 1u)

**Parameters:**
- ext_a (keyID 7): BotLen=19.6, BodyOffsetY=-1.80
- ext_b (keyID 8): BotLen=22.5, BodyOffsetY=-3.25

## Key Learnings

1. **Always use CGAL for convex key renders** — Manifold hides artifacts that
   appear in CGAL STLs.

2. **Symmetric body + offset stem beats tapered offset** — Initial approach
   used tapered BodyOffsetY (full at bottom → 0 at top). This made body
   asymmetric at intermediate heights. Constant offset on body+inner+dish with
   tapered stem transition works correctly and looks symmetric from above.

3. **pitch=0 on dish first segment makes the dome flat** — Use pitch=-3 (matching
   R3x 1u) for smooth dome curvature. pitch=0 was only needed for the failed
   tapered-body approach.

4. **Dish arc must cover the widest body cross-section** — For T1's left_line
   that extends to x≈-12.4mm, arc must be ≥13. For symmetric ext keys with
   BotWid=17.20, R3x 1u arcs (8.5/8.7) suffice.

5. **Left_line causes a small sector skin artifact** — The asymmetric polygon
   from left_line creates a persistent notch at the outer corner of the sector
   trim skin. No dish parameter change fixes it. Considered acceptable.

## Key Files

- `Choc_Chicago_Steno_Thumb_Trap.scad` — Trap keys T1/T2/T3
- `Choc_Chicago_Steno_Convex.scad` — Convex keys including ext_a/ext_b
- `gen_sprued_keycaps.scad` — Routes keycap names to modules
- `go60_visualization.scad` — V2 thumb row layout (`left_thumb_keys_v2`)

## Test Commands

Render individual keys (use CGAL backend):

```bash
# Trap keys
openscad --backend=CGAL --render --export-format binstl \
  -D 'test_keyID=0' -D 'test_dish="convex"' -o stl/debug/trap_t2.stl test_trap.scad
openscad --backend=CGAL --render --export-format binstl \
  -D 'test_keyID=1' -D 'test_dish="thumb"' -o stl/debug/trap_t3.stl test_trap.scad
openscad --backend=CGAL --render --export-format binstl \
  -D 'test_keyID=2' -D 'test_dish="convex"' -o stl/debug/trap_t1.stl test_trap.scad

# Extended R5 keys
openscad --backend=CGAL --render --export-format binstl \
  -D 'test_keyID=7' -o stl/debug/r3x_ext_a.stl test_ext.scad
openscad --backend=CGAL --render --export-format binstl \
  -D 'test_keyID=8' -o stl/debug/r3x_ext_b.stl test_ext.scad
```

Check for: `Simple: yes`, `Volumes: 2`, no visible holes/spikes/notches.

**IMPORTANT**: Always use CGAL for convex key test renders. Manifold hides
artifacts that appear in the CGAL-exported STL.

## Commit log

2026-03-15 Add Go60 keycap export files for JLC3DP
    Add R1 (steep top row) keycap definitions for boards with 4 finger rows.
    Create 7 export files for the MoErgo Go60 split ergonomic keyboard:
    - Regular columns (C3, C4): plain, homing bar, and homing dot variants
    - Lateral columns (C1, C2, C5, C6): plain, homing bar, and homing dot variants
    - Thumb cluster with convex middle keys and convex spare keys
    Row sculpt: R1(5.5mm/7°) -> R2(4.9mm/5°) -> R3(4.5mm/0°) -> R4(4.9mm/5° reversed)
    https://claude.ai/code/session_01B9t4d58zYwPBEJAQwkomVv
    [export_go60_lateral_columns.scad, export_go60_lateral_columns_homing_bar.scad, export_go60_lateral_columns_homing_dot.scad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]
2026-03-15 Add Go60 full keyboard visualization file
    Places all keycaps at approximate positions using choc spacing (18x17mm)
    with estimated column stagger and thumb arc. Shows both halves with the
    full R1->R2->R3->R4 sculpt, lateral columns, and thumb cluster.
    Not for printing - for previewing contours in OpenSCAD (F5/F6).
    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
    [go60_visualization.scad]
2026-03-16 Add generated Go60 STLs and fix Thumb dish parameters for R1
    Fix missing dish parameters (FTani, FTanf, BTani, BTanf, TanEX,
    PhiInit, PhiFin) for R1 and R3-flat entries in Choc_Chicago_Steno_Thumb.scad,
    needed for lateral R1 keycap rendering.
    Add 4 rendered STL files (lateral columns still rendering):
    - go60_regular_columns.stl
    - go60_regular_columns_homing_bar.stl
    - go60_regular_columns_homing_dot.stl
    - go60_thumbs.stl
    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
    [Choc_Chicago_Steno_Thumb.scad]
2026-03-16 Fix SecondaryDishParam alignment in Thumb module, add lateral STL
    Add missing SecondaryDishParam entries for keyIDs 9-14 (1.75u, highpro,
    R2 ALT, R1 Steep, R1 Mild) to fix recursion error when rendering
    lateral R1 keycaps.
    Add go60_lateral_columns.stl (remaining lateral homing STLs still rendering).
    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
    [Choc_Chicago_Steno_Thumb.scad]
2026-03-17 Add R1 single key STLs and re-render R2 keys
    Add new R1 row single keycap STLs (cs_r1_1, cs_r1_lateral_l,
    cs_r1_lateral_r) and re-render R2 keys for verification.
    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
    [cs_r1_1.stl, cs_r1_lateral_l.stl, cs_r1_lateral_r.stl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]
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2026-03-17 Re-render R2 lateral and R3 single key STLs with higher quality
    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
    [cs_r2x_1.stl, cs_r3_1.stl, cs_r3_125.stl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]
2026-03-17 Fix missing ChocV1 prongs in Regular and Convex keycap variants
    Move stem parts (choc_stem + transition skin) outside the body
    difference() block as implicit union siblings, and remove per-layer
    rotation from stem transition skin. This works around a CGAL
    applyUnion3D assertion failure triggered by nonplanar faces in the
    skin() output when combined with the rotated body shell.
    The thumb variant was already structured this way and unaffected.
    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
    [Choc_Chicago_Steno.scad, Choc_Chicago_Steno_Convex.scad]
2026-03-18 Add render_all_keys script and re-render R1 keycaps
    Add scripts/render_all_keys.sh for batch rendering all single keycap
    STL files via OpenSCAD. Re-rendered R1 keycaps with latest fixes.
    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
    [cs_r1_1.stl, cs_r1_lateral_l.stl]
2026-03-18 Re-render cs_r1_lateral_r STL with prong fix
    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
    [cs_r1_lateral_r.stl]
2026-03-18 Revert CSG tree restructuring that broke top surface geometry
    The restructuring in 27e1e7f moved the stem transition outside the
    dish difference() and removed per-layer StemRotation, which caused
    a visible dividing line on the top surface with different heights
    on each side. Reverting to the original CSG tree structure.
    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
    [Choc_Chicago_Steno.scad, Choc_Chicago_Steno_Convex.scad]
2026-03-18 Re-render R2 keycap STLs with restored CSG tree
    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
    [cs_r2_1.stl, cs_r2_125.stl, cs_r2_15.stl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]
2026-03-19 Re-render R1 and R2_1 keycap STLs with restored CSG tree
    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
    [cs_r1_1.stl, cs_r1_lateral_l.stl, cs_r1_lateral_r.stl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]
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2026-03-25 Fix typo: keyId -> keyID in thumb stem layer addition
    The variable was misspelled as `keyId` (lowercase d) instead of `keyID`
    on line 393, causing OpenSCAD to treat it as an unknown variable. This
    meant the 2u thumb key (keyID == 4) never got its stemLayerAddition of 8,
    and likely caused thumb keys to fail to render in the visualization.
    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
    [Choc_Chicago_Steno_Thumb.scad]
2026-03-25 Fix thumb row positioning in Go60 visualization
    Thumb row now starts at column 2 (C4/ring finger) instead of column 0.
    First 3 keys are straight-aligned with finger columns, then the remaining
    3 keys fan out with ~12.5° progressive splay per key, pivoting around
    the edge of the last straight key.
    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
    [go60_visualization.scad]
2026-03-25 Adjust thumb cluster to better match Go60 layout from reference image
    - Reduced splay from 12.5° to 10° per key to match the visible arc
    - Moved thumb row closer to finger keys (18mm gap instead of 22mm)
    - Adjusted pivot point to boundary between straight and splayed keys
    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
    [go60_visualization.scad]
2026-03-26 Fix dish seam artifacts for Manifold renderer and re-render all STLs
    The dish was built from two separate skin() sweeps (front + back) that
    met at the center with a tiny .0001 offset. CGAL handled this seam
    gracefully but Manifold produced visible ridges and non-manifold geometry.
    Fix by combining front and back dish sweeps into a single continuous
    DishCurve skin. For the Convex variant (which uses different rotations
    for front/back), pre-apply the rotation matrices to each profile before
    combining. Also remove the D-shape closing points from Convex DishShape
    that caused self-intersections when swept.
    Additionally, fan-triangulate the skin() end caps (libraries/skin.scad)
    to avoid nonplana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
    [Choc_Chicago_Steno.scad, Choc_Chicago_Steno_Convex.scad, Choc_Chicago_Steno_Thumb.scad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]
2026-03-26 Fix stem transition causing non-manifold geometry on Manifold backend
    - Regular/Convex: skip stem transition skin when Z range <= 0 (degenerate
    flat disc that Manifold can't handle)
    - Thumb: clamp StemTransform profile ratio to 1.0 so stemLayerAddition
    doesn't grow profiles beyond the body shell size
    Result: 40/43 keys now genus=0. The 3 remaining convex keys (cs_r2x_1,
    cs_r3x_1, cs_r4x_1) have genus 2-3 from a Manifold Boolean interaction
    between the hollow body+stem union and the pre-rotated combined dish —
    each piece is individually genus=0 but their combination produces minor
    topology artifacts. Visual output is clean for all keys.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
    [Choc_Chicago_Steno.scad, Choc_Chicago_Steno_Convex.scad, Choc_Chicago_Steno_Thumb.scad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]
2026-03-26 Fix convex keycap dish for OpenSCAD 2026 CGAL and re-render with CGAL
    Restore original two-sweep dish approach and DishShape closing points
    for the convex variant. The combined single-sweep approach used for
    Regular/Thumb doesn't work for Convex due to the different front/back
    rotations creating invalid geometry with Manifold.
    Add 0.01° XAngleSkew perturbation to R3x keys (was exactly 0) to work
    around a CGAL assertion failure in OpenSCAD 2026 where perfectly
    symmetric front/back dish sweeps create degenerate overlapping geometry
    that the newer CGAL cannot convert to Nef polyhedra. The perturbation
    is imperceptible but breaks the exact symmetry.
    Convex STLs rendered with CGAL backend (Man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
    [Choc_Chicago_Steno_Convex.scad]
2026-03-26 Document convex CGAL requirement and wire up render script
    Add rendering notes to Choc_Chicago_Steno_Convex.scad explaining why
    CGAL is required and the R3x XAngleSkew perturbation.
    Update render_all_keys.sh to route convex keys (cs_r*x_*) to CGAL
    backend automatically.
    [Choc_Chicago_Steno_Convex.scad]
2026-03-28 Fix convex stem geometry and thumb 1.25u dish, restructure Go60 export plates
    Two geometry fixes for the alt thumbs plate (export_go60_thumbs_alt):
    1. Convex keycap stems (cs_r2x_1, cs_r4x_1) were missing because keyID 0
    has only 3.8mm height vs 2mm top thickness + 1.8mm stem cross, leaving
    negative Z travel for the stem transition skin. The rotated cross-sections
    also produced nonplanar quad faces that caused CGAL assertion failures.
    Fix: ensure minimum 0.5mm Z travel, remove rotation from stem transition
    (translation-only, matching the thumb file approach), add stemLayerAddition
    for tight-clearance keys, and clamp transform/radius functions.
    2. Thumb 1.25u (cs_t_125_l/r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
    [Choc_Chicago_Steno_Convex.scad, Choc_Chicago_Steno_Thumb.scad, cs_r1_lateral_l.stl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]
2026-03-30 Widen thumb plate spacing and add Go60 docs to README
    Increase sprue spacing from 18mm to 20mm for both thumb plates so
    the gap between keys (~2.8mm) matches the vertical plates (~2mm),
    since unrotated thumb keys present their wider dimension (17.2mm)
    along the spacing direction.
    Also add Go60 plate table and rendering notes to README, and update
    STL reference since STLs are now gitignored.
    [export_go60_thumbs.scad, export_go60_thumbs_alt.scad]
2026-03-30 Fix thumb 1.25u dish not clearing corners
    The dish arc radii and tangent radii were interpolated too conservatively,
    leaving uncut slivers at the SE and NW corners. Widen FrontFinArc 17→20,
    BackFinArc 18→20, ForwardTanInit 4.2→5, BackTanInit 1.5→2.
    [Choc_Chicago_Steno_Thumb.scad]
2026-03-30 Add binary STL docs and missing 1.25u keys to render script
    - Document --export-format binstl in README (6x smaller output)
    - Add binstl flag to render_all_keys.sh
    - Add cs_t_125_l/r to render script key list
2026-03-31 Add spare ridged thumb keys to Go60 lateral columns plate
    Fills the lateral_columns plate from 8 to 10 keys by adding cs_t_1_l
    and cs_t_1_r spares — the only non-convex keys with zero spares across
    all Go60 plates. Updates README totals (76 → 80).
    [export_go60_lateral_columns.scad]
2026-04-02 Update Go60 visualization with measured layout geometry
    Replicate the real Go60 key layout from reference photography using
    OpenCV-based key detection to extract precise positions:
    - Non-uniform column spacing (hybrid ~17.9/18.9mm) via per-column
    X position array instead of uniform col_spacing
    - Column stagger measured from photo: C6/C5 drop 0.79 rows, C4/C2
    drop 0.17 rows, C1 drops 0.26 rows (C3 = reference)
    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
    [go60_visualization.scad]
2026-04-02 Add trapezoidal sector-shaped keycaps for Go60 splayed thumb positions
    New keycap module (variation 4) generates sector-shaped keycaps that
    fill the wedge gaps between arc-splayed thumb keys. Three key types:
    - T1 (cs_t_trap_convex_t1): Convex dome, inner edge aligned to C1
    column, depth tapers from 1u (16mm) to 1.25u (20mm)
    - T2 (cs_t_trap_convex): Convex dome, symmetric 1.25u sector
    - T3 (cs_t_trap_thumb_l/r): Thumb scoop, symmetric 1.25u sector
    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
    [Choc_Chicago_Steno_Thumb_Trap.scad, gen_sprued_keycaps.scad, go60_visualization.scad]
2026-04-02 Add trapezoidal keycap docs to README and visualization header
    Document the new sector-shaped keycap variants in README section 3.1.8
    with a table of available keycap IDs, profiles, and features. Update
    Go60 section to reference the trapezoidal keys in the visualization.
    Update go60_visualization.scad header to describe the T1/T2/T3 keycap
    types and their properties.
    [go60_visualization.scad]
2026-04-02 WIP: Fix trapezoidal keycap dish rendering, document remaining issues
    Fixed bugs:
    - DishShape() used wrong ellipse range and missing extension points
    - Convex back trajectory used backward instead of forward
    - Convex dish sweep too short for BotLen=20 keycaps
    - sector_rectangle point density 4x too low (60 vs 240 points)
    Current approach (needs refinement):
    - Build smooth elliptical_rectangle body, apply dish, then intersect
    with sector shape. Top surfaces are clean but side edges are wavy
    where the elliptical body shows through the sector trim.
    See TODO_trap_keycap_fixes.md for full analysis and next steps.
    [Choc_Chicago_Steno_Thumb_Trap.scad]
2026-04-02 WIP: Fix trap keycap dish artifacts with oversized body, extended dish, corner chamfers
    Three-pronged approach to eliminate dish-corner artifacts on T1/T2/T3:
    1. Oversized smooth body: elliptical outer shell +[8,8] (4mm/side) so
    the sector trim exclusively determines edge shape. Dish operates on
    smooth surface without seeing sector corners.
    2. Extended dish coverage: increased convex arcs 10.75→14.0 and forward
    distances 10.5→14.0mm; thumb arcs 16/20→20/24 and forward 12→16mm.
    Ensures dish reaches all sector corners including T1's extended right
    side (depth_ratio 10/9) and T3's skew-shifted high side.
    3. Corner chamfers: sector_rectangle fillet=0.5mm shortens edges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
    [Choc_Chicago_Steno_Thumb_Trap.scad, test_trap.scad, view_stl.scad]
2026-04-03 Fix trap keycap dish: sharp corners, visible dome curvature
    Remove corner chamfers (fillet 0.5→0) that created visible "chopped off"
    corners. Tune convex dish arcs from flat 14/14.5 to 10.5→13 gradient
    that widens along the sweep — initial arc gives visible dome curvature
    on the narrow sector footprint, final arc provides safe corner coverage
    for T1's depth_ratio 10/9 extended right side.
    [Choc_Chicago_Steno_Thumb_Trap.scad]
2026-04-05 WIP: Add v2 thumb row with symmetric T1 + extended R5 keys
    T1 v2 (keyID 3): symmetric depth (BotLen=20, depth_ratio=[1,1]),
    uniform arc dish (no curvature change), left_line C1 alignment.
    Clean render except persistent left_line notch at outer-right corner.
    Extended R5 keys (keyIDs 7, 8): BodyOffsetY in convex module shifts
    body asymmetrically to extend bottom to y=-57 (aligned with T1 v2).
    ext_a (C4/C2 R5, +3.6mm): clean. ext_b (C3 R5, +6.5mm): has spike
    from dish not covering the larger offset at intermediate heights.
    Next: make ext keys look symmetric from above (body+dome centered,
    stem offset below). Needs different approach to avoid CGAL boolean
    issues with constant BodyOffsetY.
    Als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
    [Choc_Chicago_Steno_Convex.scad, Choc_Chicago_Steno_Thumb_Trap.scad, gen_sprued_keycaps.scad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]
2026-04-05 Symmetric body for ext R5 keys: body+dish centered, stem offset
    Replace tapered BodyOffsetY (full at bottom → 0 at top) with constant
    offset so body and dish are symmetric at all heights. Stem transition
    tapers from y=0 (switch) to y=BodyOffsetY (inner shell) to bridge the
    gap. Dish params use symmetric front/back sweeps.
    Both ext_a and ext_b now pass CGAL (Simple: yes, Volumes: 2).
    Previous ext_b spike is fixed.
    [Choc_Chicago_Steno_Convex.scad]
2026-04-05 Fix ext key dome curvature: pitch=-3 and arcs matching R3x 1u
    The pitch=0 first segment (needed for old tapered body approach) made
    the dome flat with sharp edge transitions. With symmetric body, use
    standard pitch=-3 and arcs=8.5/8.7 (matching R3x 1u) for smooth dome
    curvature. Both keys still pass CGAL (Simple: yes, Volumes: 2).
    [Choc_Chicago_Steno_Convex.scad]
2026-04-05 Remove T1 v1, consolidate to single T1 with improved dome
    Remove keyID 2 (T1 v1 with asymmetric depth taper), renumber T1 v2
    to keyID 2 as the only T1. Update all references in gen_sprued and
    go60_visualization.
    T1 dish params: pitch=-3 (was 0) for smooth dome curvature, uniform
    arc=13 (was 14) to cover left_line corner at x≈-12.4mm. Forward
    distances match T2 (8+6/7+5).
    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
    [Choc_Chicago_Steno_Thumb_Trap.scad, gen_sprued_keycaps.scad, go60_visualization.scad]
2026-04-16 Update docs for symmetric ext keys and consolidated T1
    README: Fix T1 description (no longer tapered depth, just symmetric
    1.25u with C1-aligned inner edge). Add section 3.1.9 documenting
    the extended R5 keys (ext_a/ext_b) used in the V2 thumb row.
    TODO: Rewrite to reflect current state — all keys working, ext keys
    use symmetric body approach, T1 v1 removed, T1 uses pitch=-3 with
    uniform arc=13. Document both architectures and key learnings.
2026-04-28 Add non-lateral C1+C2 plate for Go60 with homing keys
    New export_go60_regular_columns_homing.scad bundles ridged R1-R4 for
    two columns plus cs_r3_1_bar / cs_r3_1_dot homing keys for C2 R3,
    filling the gap when printing the non-lateral version of the inner
    index pair. README's Go60 table now documents both lateral and
    non-lateral styles (12 plates / 120 keys for both).
    [export_go60_regular_columns_homing.scad]
2026-07-29 Document why V2 puts a convex dome on C2 R5
    V1 (left_thumb_keys) deliberately uses cs_t_1_l — a thumb dish — at
    C2 R5: the thumb rests on T1 and reaches C2 R5, while C3/C4 R5 are
    finger keys. V2 replaced all three straight R5 keys with extended
    convex caps, not as a shape decision but because BodyOffsetY lives
    only in Choc_Chicago_Steno_Convex.scad and no extended thumb variant
    exists, so the three positions collapsed onto the one available shape.
    Comments only, no geometry change. Fixing it properly means porting
    BodyOffsetY into the thumb file, where the 7mm scoop should be
    expected to spike the way ext_b did.
    [go60_visualization.scad]
